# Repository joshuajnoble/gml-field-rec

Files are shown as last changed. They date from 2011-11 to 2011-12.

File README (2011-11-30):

WARNING: WORK IN PROGRESS...

configuring Eagle
-----------------

(B) setup environment in Eagle (library, schematic, layout)
  (1) in Eagle choose Options/Directories
  (2) add EAGLE diretory to Libraries (seperate paths with ':')
  (3) add EAGLE directory to Projects
  (4) in main Eagle window, under Projects, enable the fieldrec.lbr by clicking in the small grey circle (become green when enabled)

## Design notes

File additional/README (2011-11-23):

This library/code sample is to demonstrate writing GML to an SD card. I'd like to expand it to stream over RF as well. You do need to add one method to the WString class to get it work properly though:

char* c_str() { return _buffer; }

this mimics the c++ string method.

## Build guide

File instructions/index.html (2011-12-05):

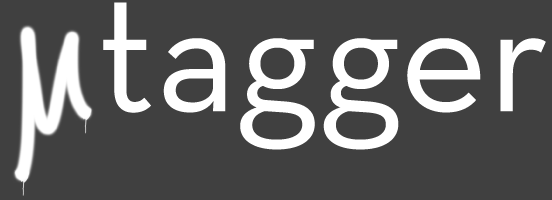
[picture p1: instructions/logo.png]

GML Field Recorder

# What Is This?

It's my entry for the GML Field Record Challenge which you can read more about here. What's GML you ask? Good question! Maybe this video will help:

So now you know a little about what GML is, you can understand why it would be cool to have something that could record GML out in the field, right? So what do we have? We got this:

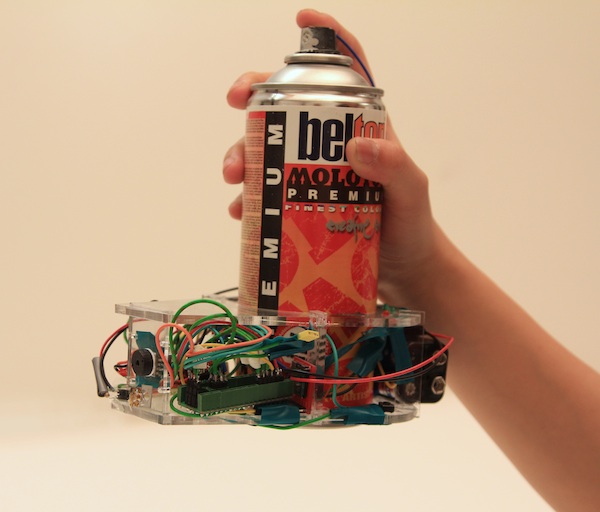
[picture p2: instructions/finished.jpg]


Looks crazy, right? I know. It kind of does. But it's also made to be built by anyone. Yes, anyone. Even you. So let's get down to it! First things first, you'll need to buy stuff.

# Buying Stuff

So you wanna make a μTagger GML Field Recorder? Great. First things first: you need to buy some electronics. The challenge says:

Material costs for the field device must not exceed 300 euros. Computers and equipment outside of the 300 euros can be used for non-field activities (such as downloading and manipulating data captured in-field), but at the time of capture a graffiti writer should have no more than 300 euros worth of equipment on him or herself.

Let's make a list in US Dollars, so I don't have to convert back everything I bought from US suppliers. We've got ~420.39$US to spend, so let's spend it.

- Teensy++2.0 $24
- ADNS5050 $1.47
- Ultrabright LED RED $4 example (http://www.sparkfun.com/products/9634)
- 2 100uF Ceramic Capacitors $1
- 2 1mF Capacitors $1
- Some Wires $3
- Sparkfun 9DOF $99 here (http://www.sparkfun.com/products/10724)
- 3 LEDs $2
- 2 220uF Capacitors $1
- 1 100uF Capacitor $0.50
- 1 1mO Resistor $0.50
- 1 Camera lens ~$10 (for the camera but you'll tear it apart)
- MicroSD card 2GB $4
- 1 3.3V Voltage Regulator $3
- MicroSD card holder $4 OR
- MicroSD card shield $10 here (http://www.sparkfun.com/products/544)
- Aluminum Foil $0.50
- Pushbutton $1

= $170.97 or 126.81 Euros
Not too shabby.
Where can I get this stuff?
Sparkfun (http://www.sparkfun.com/)
DigiKey (http://www.digikey.com/)
Mouser
RS

# How Does It Work?

Basic theory of operation goes like so: it's an optical mouse that knows how it's being tilted. We need to make sure that the mouse can read properly off the wall so we need to illuminate the wall properly, hence the ultra-bright Red LED. This one is 640nm, which is close enough to the 680nm that the ADNS5050 really wants. If you find a really bright 680nm LED that'll work even better. It needs to be big and bright though because we're working with a much larger area than the optical mouse is used to working with.

We point the mouse sensor and lens and LED at the wall and we get tracking. Easy right? Not really. There's a lot of fussing around to get the lens mounted correctly and aimed correctly at the optical mouse senors actual optical sensor. I got a lens that was f3.8, which is pretty perfect for what I want to do. You might get a different one, but if it's possible, stick with f3.8. Some of the keychain cameras come with f4.7 which isn't really going to work as well. We want something close up.

Making the lens mount is somewhat tricky and requires that you learn a little bit about the lens law depending on what the foal length of your lens is. As I mentioned, I'm using a f3.8 lens pulled out of a camera like the one shown below:

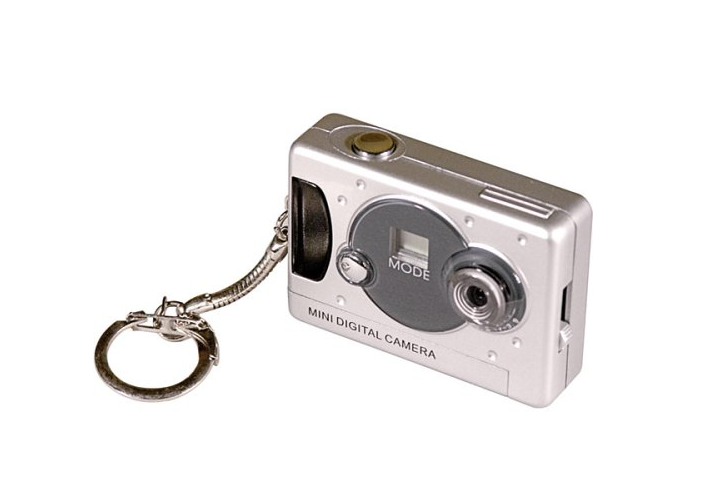
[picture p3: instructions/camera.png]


The lens law looks like this:



You can translate that as: 1/distance from lens to focal plane + 1/distance from lens to object = 1/focal length.

What that means is that whatever your lens is, f3.8, f4.9, whatever, you need to balance the equation with the reciprocal of the distance of the object to the lens plus the reciprocal of the distance of the lens to the focal plane. I've got mine set up a 5.25mm distance from between the lens and the ADNS5050 so that I can focus on things around 2.5cm away from the lens (do the math if you like). Whatever lens you decide to use, just make sure that the radius of the focal area is small. Those little keychain cameras are perfect, larger lenses, like the ones from the PS3 eye, aren't going to work. NOTE: the actual location of the optical sensor in the ADNS5050 is 2mm down from the top of the optical mouse sensor. See the picture here:

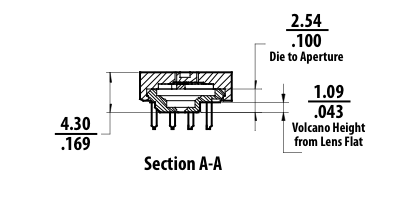
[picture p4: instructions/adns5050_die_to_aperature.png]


So your actual distance from the die to the aperature is 1mm from the start. You need to get 4.25 more mm for all to be happy.

# Cutting Stuff Up

I cut the lens mount and the ADNS5050 holder out of 2mm acrylic on a cheap shitty laser cutter. Works like a dream. The illustrator file is included. The difficulty is positioning the lens just right so that it's 5.25mm from the optical mouse sensor. I made a mount out of two pieces of two pieces of acrylic and put some little holes in them to ensure that everything lined up right.

Here's the cuts for the frame as they came out:

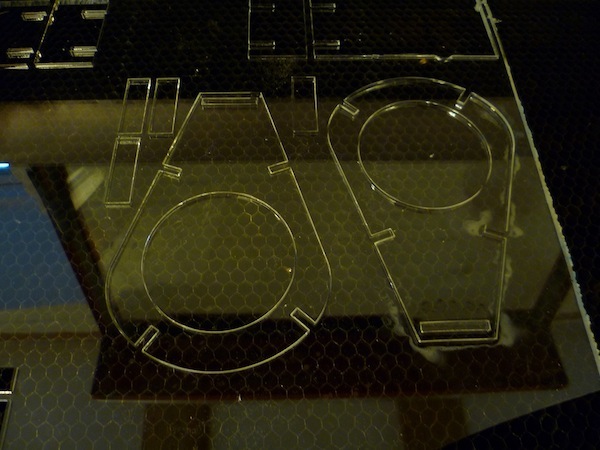
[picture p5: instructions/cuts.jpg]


Here's what the holders look like close up.

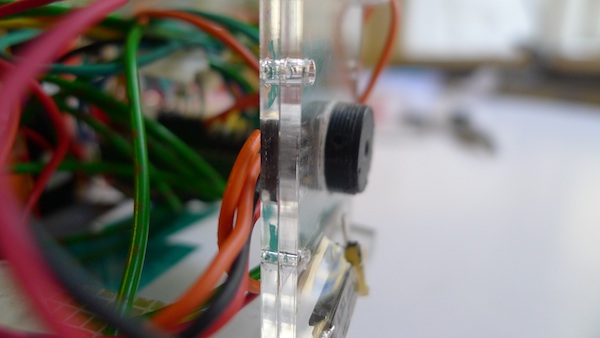
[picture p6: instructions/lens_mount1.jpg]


You can see how the ADNS5050 is behind the lens, with the wires soldered in place:

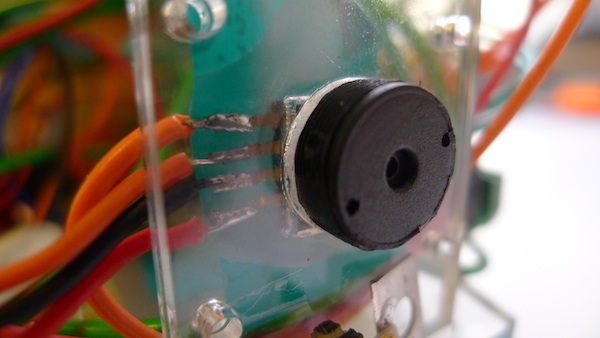
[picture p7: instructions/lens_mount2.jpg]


The lens mouse illustrator files are included as lens_mount.ai
The body of the field recorder is shown in shape_pattern.ai
It's fairly rough right now, v2 is going to have a better shaped body.

# Putting It Together

The Teensy sits on the body, with all the wiring and 4 AA batteries. The teensy can't handle a 9V battery, so don't plug one into it. The lens+ADNS assembly slots into the little cutout at the end. Right now I have it so it's fit tight with the 2 sheets of 2mm acrylic that make up my assembly, but whatever holds it perpendicular to the wall and doesn't allow it to move is just fine. The body is then slid over the bottom of the spray paint can and held into place with some pieces of tape. I also added some into place (tape not neccessary, but recommended).

The 9DOF is mounted along the side the can where there's room.

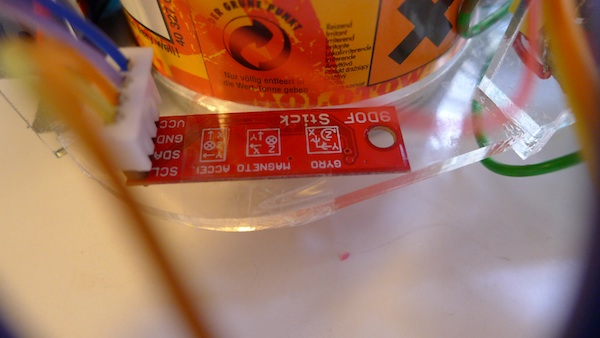
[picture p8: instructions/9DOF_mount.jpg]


It's pretty important how this thing is mounted because it affects the positioning data that you'll get back. In the code you might note this:

if(abs(p) > 0.1) /// some arbitrary-ish noise amount
{
xRot = sin(ypr[1] + (TWO_PI));
yRot = cos(ypr[1] + (TWO_PI));
position[0] += xRot;
position[1] -= yRot;

}

That's actually dependent on the positioning of the 9DOF so if you move it, those'll need to be different.

The capacitive sensor uses a piece of foil to read the touches when the user is actually making a line. You should put near the top of the can so that it's easy to spray and signal to the recorder that you're making a line at the same time. How about the actual tag trigger? Pretty straightforward:

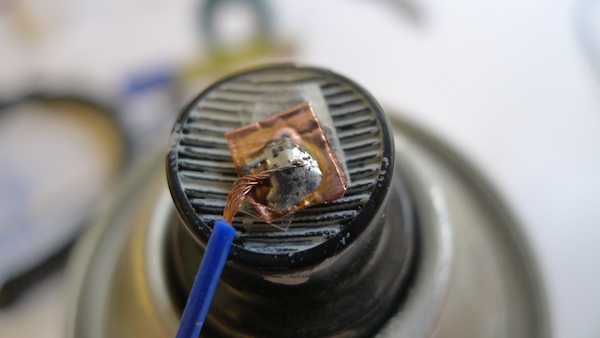
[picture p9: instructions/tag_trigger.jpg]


Yep, that's copper tape with a wire soldered to it and that's all you need.

# Using It

Here's the manual:

- Start up the field recorder by plugging in the battery.
- If the SD Card is full or there's another problem with it, the SD card LED is flashed 5 times to let you know. Otherwise, it illuminates for 1 second.
- When you press the toggle button, you start recording a tag. The recording light goes on to let you know that the tag is being recorded.
- When you press on the capacitive sensor the recording LED and the SD card LED will go on to let you know that the stroke is being recorded. When it's released the SD card LED goes out. This givs you an idea of what's going on in the recorder. You can use the surface quality LED to see how well your ADNS5050 is recognizing the surface. If the light is steadily illuminated, it's doing very well; the more slolwy the light blinks, the worse the signal quality and the worse the accuracy of your recorded tag will be.
- As you move the recorder around it's important to keep it oriented perpendicular to the wall. The beta version of the software will be much better about allowing you to move the recorder around a little more but for the moment the mouse sensor is the only thing really recording the position, so it's important that it works well. Right now the sensor is 0.5 centimeter precise when used correctly, but I'm working on it, and hopefully I'll get to mm precision soonish. Just a little bit more math and noise filtering to use the 9DOF better. If you've set the lens so that it should be focused at 2cm, then make sure you keep it at 2cm. Again, this is going to get better in the v2 or beta release, or whatever, but tat the moment it's a bit naive, so bear that in mind when making a tag.
- The surface quality light blinks slower and slower as the surface quality goes down. Your goal when operating the thing should be to keep the surface quality light as close to constantly illuminated as possible
- When you're done with your tag simply press the button again and you'll see the tag light either blink 3 times slowly for a happy write to file or 5 times quickly for a failed write to file.

# The Code

Most of the main application is contained in libraries. Everything in /libs goes in your Arduino/libraries
You need to add one method to the WString class to get it work properly though:

char* c_str() { return _buffer; }

this mimics the c++ string method. The WString.h lives where Arduino application lives, so Arduino/hardware/teensy/cores on Windows or Arduino.app/Resources/Java/hardware/teensy/cores on OSX. You can either add that manually or copy the files from /additional There are two extra config applications to help you position the lens correctly, an Arduino application and a Processing application (https://github.com/joshuajnoble/gml-field-rec/tree/master/configuration). The P5 app just reads the pixels from the ADNS5050 so you can focus the lens, check your positioning and the distance from the lens to the mouse sensor.

# The Future

- As mentioned, I need to make a better body for the thing.
- Make a video.
- Try out some different optical sensors like the ADNS9550 for higher resolution.
- I'm making an ipod/iPhone OF app that you can use with a simple chip plugged into the bottom of the iPhone to grab signals directly from the tagger and live log.
- We're building an eagle file to print an actual board instead of the DIY jiggedy-ness that we have at the moment.

# DOWNLOAD HERE (http://thefactoryfactory.com/GML_FR.zip)

# GITHUB HERE (https://github.com/joshuajnoble/gml-field-rec)

joshua noble 2011 no rights reserved, long live christiania

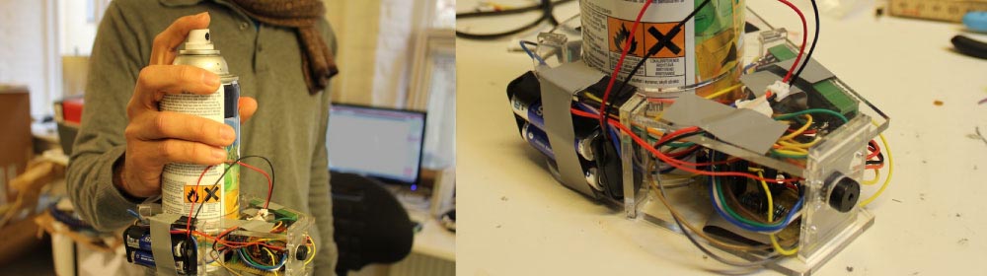
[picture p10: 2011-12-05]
instructions/headerbg.jpg

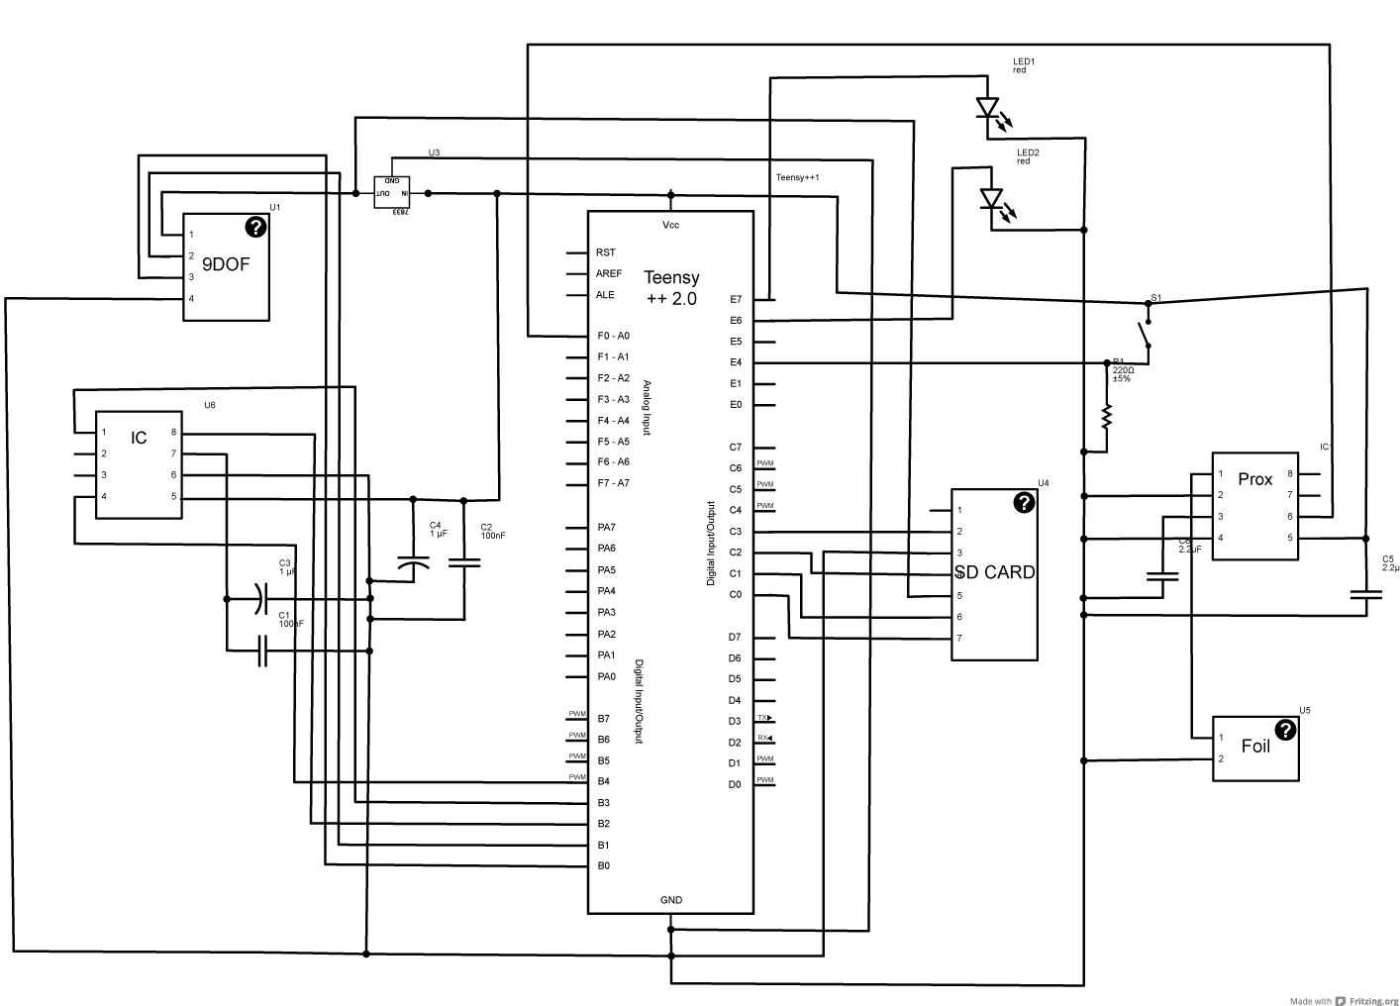
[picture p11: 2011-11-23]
wiring/gml_fieldrecorder_schem.png

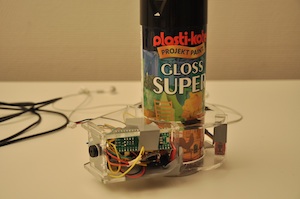
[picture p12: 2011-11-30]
instructions/header2.jpg

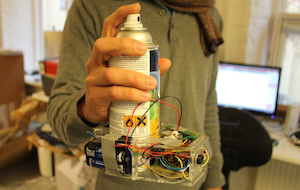
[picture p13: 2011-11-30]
instructions/header.png

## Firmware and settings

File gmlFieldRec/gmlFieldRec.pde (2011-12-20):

#include "ADNS5050.h"
#include "GMLWriter.h"
#include <Wire.h>
#include <ADXL345.h>
#include <HMC58X3.h>
#include <ITG3200.h>
#include <CapSense.h>

#include <SdFat.h>

// I'm using a Teensy 2.0, but you can use any 328 or higher board.
// You do need a bigger board to run this, anything with a 168 or Atmega8
// probably isn't going to cut it
#define __AVR_AT90USB1286__
// #define __AVR_ATmega328P__ // Arduino Uno

//#define DEBUG

//#ifdef DEBUG
//  const int CAP_LIM = 2000;
//#else ifndef DEBUG
  const int CAP_LIM = 500;
//#endif

#include "DebugUtils.h"
#include "FreeIMU.h"
#include "CommunicationUtils.h"

#define TAGGING_LED 33
#define SDCARD_LED 29
#define SQUAL_LED 28
#define TAG_PIN 32

#define SCLK                11
#define SDIO                10
#define RESET_PIN           12
#define NCS                 13

#define ILLUMINATION_LED 24
#define LASER_LED 19

// STATE
int state;

#define INIT 1
#define TAGGING 2
#define TAGGING_DOWN 3
#define FINISH_TAG 4

long debounce;

//#define CAN_HEIGHT_600ML 28.4 // height of a 600ML molotow can in CM
//#define CAN_HEIGHT_12OZ 26

//#define CAN_HEIGHT_600ML 14.2 // height of a 600ML molotow can in CM
#define CAN_HEIGHT_600ML 2

ADNS5050 omouse(SCLK, SDIO, NCS, RESET_PIN); // might want to shift this over to non-PWM pins?
GMLWriter gml;

// we'll just start at 2000 so we don't go negative
float position[2] = { 
  2000.0, 2000.0 };
int pposition[2];

float ypr[3] = { 0.0, 0.0, 0.0 };
float prevYpr[3];

// Set the FreeIMU object
FreeIMU imu = FreeIMU();

long tagStart;
int surfQuality;
long lastSurfBlink;
boolean squalPin;

CapSense listenCap = CapSense(34, 30);

void setup()
{

  //Serial.begin( 9600 );
  
  omouse.sync(); // this takes a second
  
  pinMode( LASER_LED, OUTPUT);
  pinMode( ILLUMINATION_LED, OUTPUT );
  pinMode(TAG_PIN, INPUT);

  pinMode(TAGGING_LED, OUTPUT);
  pinMode(SDCARD_LED, OUTPUT);
  pinMode(SQUAL_LED, OUTPUT);

  digitalWrite( SDCARD_LED, HIGH);
  delay(500);
  digitalWrite( SDCARD_LED, LOW);
  digitalWrite( TAGGING_LED, HIGH);
  delay(500);
  digitalWrite( TAGGING_LED, LOW);
  digitalWrite( SQUAL_LED, HIGH);
  delay(500);
  digitalWrite( SQUAL_LED, LOW);

  // SD CARD SET UP
  debounce = millis();

  int ret = gml.init();
  //Serial.print( ret );
  if(ret != 1) { // i.e. if it fails

    //Serial.println(" GML not intialized ");

    int i;
    for(i = 0; i<5; i++) { // 5 blinks = not ok
      digitalWrite( SDCARD_LED, HIGH);
      delay(250);
      digitalWrite( SDCARD_LED, LOW);
      delay(250);
    }
  } 
  else {
    digitalWrite( SDCARD_LED, HIGH);
    delay(2000);
    digitalWrite( SDCARD_LED, LOW);
  }

  state = INIT;
  
  // CAPSENSE setup
  listenCap.set_CS_Timeout_Millis(30);
  listenCap.set_CS_AutocaL_Millis(10);
  
  
  // FREEIMU set up
  Wire.begin();
  //Serial.println( " set pu  ");
  delay(5);
  imu.init(); // the parameter enable or disable fast mode
  delay(5);
}


void loop()
{

  if(state == INIT)
  {
    if(digitalRead(TAG_PIN) && millis() - debounce > 500) {

      debounce = millis();

      //Serial.println(" start tagging ");

      if( gml.beginDrawing() != 1 ) {
        
        //Serial.print(" can't begin drawing ");
        
        int i;
        for(i = 0; i<5; i++) { // 5 blinks = not ok
          digitalWrite( SDCARD_LED, HIGH);
          delay(500);
          digitalWrite( SDCARD_LED, LOW);
          delay(500);
        }
        return;
      }

      state = TAGGING;
      
      digitalWrite(TAGGING_LED, HIGH); // know you're tagging
      digitalWrite( ILLUMINATION_LED, HIGH );
      digitalWrite( LASER_LED, HIGH);

      return;
    }
  }
  else if (state == TAGGING)
  {
    //delay(10);
    ////Serial.println(" TAGGING ");
    tagStart = millis();

    if(digitalRead(TAG_PIN) && millis() - debounce > 500) {
      debounce = millis();
      //Serial.println(" tag pin ");
      state = FINISH_TAG;
    }
   
   byte sqty = omouse.surfaceQuality();
   if(sqty != -1) { // sometimes this just returns nothing
     surfQuality = 80 - (sqty * 4);
   }
   
    if(surfQuality < 2) {
      digitalWrite(SQUAL_LED, HIGH);
    } else if(millis() - lastSurfBlink > surfQuality) {
      lastSurfBlink = millis();
      digitalWrite(SQUAL_LED, squalPin);
      squalPin = !squalPin;
    }
    

    imu.getYawPitchRoll(ypr);
    determinePosition();
    
    int cap = listenCap.capSense(10);
    if(cap > CAP_LIM || cap < -1) // this is for my configuration, yrs may differ
    {
      digitalWrite(SDCARD_LED, HIGH);
      state = TAGGING_DOWN;
      gml.beginStroke();
    }
    
  }
  else if (state == TAGGING_DOWN)
  {
    determinePosition();

    ////Serial.println( omouse.surfaceQuality(), DEC );
    
   byte sqty = omouse.surfaceQuality();
   if(sqty > 0) { // sometimes this just returns nothing
     surfQuality = 80 - (sqty * 4);
   }
    
    if(surfQuality < 2) {
      digitalWrite(SQUAL_LED, HIGH);
    } else if(millis() - lastSurfBlink > surfQuality) {
      lastSurfBlink = millis();
      digitalWrite(SQUAL_LED, squalPin);
      squalPin = !squalPin;
    }
    
    int cap = listenCap.capSense(10);
    if(cap > CAP_LIM || cap < 0)
    {

      if( abs(pposition[0] - position[0]) > 1.0 ||  abs(pposition[1] - position[1]) > 1.0) {
        gml.addPoint(position[0], position[1], millis() - tagStart);
      }

      pposition[0] = position[0];
      pposition[1] = position[1];

    }
    else
    {
      digitalWrite(SDCARD_LED, LOW);
      debounce = millis();
      state = TAGGING;
      gml.endStroke();

    }
    
  }
  else if(state == FINISH_TAG)
  {
    //if(gml.endDrawing()) {

    digitalWrite( ILLUMINATION_LED, LOW );
    digitalWrite( LASER_LED, LOW);

    if(gml.endDrawing()) {

      //Serial.println(" FINISH_TAG OK ");

      digitalWrite(TAGGING_LED, LOW); // know you're tagging
      digitalWrite( SDCARD_LED, HIGH);
      delay(1000);
      digitalWrite( SDCARD_LED, LOW);
      delay(500);
      digitalWrite( SDCARD_LED, HIGH);
      delay(1000);
      digitalWrite( SDCARD_LED, LOW); // 2 blinks, it's ok


    } else {

      //Serial.println(" FINISH_TAG NOT OK ");

      digitalWrite(TAGGING_LED, LOW); // know you're tagging

      int i;
      for(i = 0; i<5; i++) { // 5 blinks = not ok
        digitalWrite( SDCARD_LED, HIGH);
        delay(500);
        digitalWrite( SDCARD_LED, LOW);
        delay(500);
      }
    }
    digitalWrite( SQUAL_LED, LOW);
    state = INIT;
  }
}

void determinePosition()
{

  position[0] -= omouse.dx() >> 1;
  position[1] -= omouse.dy() >> 1;

  float y, p, r;

  imu.getYawPitchRoll(&ypr[0]);

  y = prevYpr[0] - ypr[0];
  p = prevYpr[1] - ypr[1];
  r = prevYpr[2] - ypr[2];
  
  float xRot, yRot;

  if(abs(p) > 0.1) /// some arbitrary noise amount
  {
    //xRot = sin(ypr[1] * (PI/180.0) + (TWO_PI));
    //yRot = cos(ypr[1] * (PI/180.0) + (TWO_PI));

    xRot = sin(ypr[1] + (TWO_PI)) * CAN_HEIGHT_600ML;
    yRot = cos(ypr[1] + (TWO_PI)) * CAN_HEIGHT_600ML;
    
    position[0] -= xRot;
    position[1] -= yRot;
    
  }

  prevYpr[0] = ypr[0];
  prevYpr[1] = ypr[1];
  prevYpr[2] = ypr[2];

  /*Serial.print(ypr[1]);
  //Serial.print(" ");
  //Serial.print(position[0]);
  //Serial.print(" " );
  //Serial.println(position[1]);*/

}

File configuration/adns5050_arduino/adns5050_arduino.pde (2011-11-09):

#define SCLK                10
#define SDIO                11
#define RESET_PIN           12
#define NCS                 13
#define POWER               17

#define PRODUCTID          0x00 // should be 0x12
#define PRODUCTID2          0x3e //should be 0x26
#define REVISION_ID         0x01
#define DELTA_Y_REG         0x03
#define DELTA_X_REG         0x04
#define SQUAL_REG           0x05
#define MAXIMUM_PIXEL_REG   0x08
#define MINIMUM_PIXEL_REG   0x0a
#define PIXEL_SUM_REG       0x09
#define PIXEL_DATA_REG      0x0b
#define SHUTTER_UPPER_REG   0x06
#define SHUTTER_LOWER_REG   0x07
#define RESET		    0x3a
#define CPI500v		    0x00
#define CPI1000v	    0x01

#define NUM_PIXELS          360

#define MICROSEC_DELAY      10

byte pix[360];

const int LED_R = 26;
const int LED_L = 24;

void setup()
{
  Serial.begin(115200);

  pinMode(SDIO, OUTPUT);
  pinMode(SCLK, OUTPUT);
  pinMode(POWER, OUTPUT);
  
  pinMode(LED_R, OUTPUT);
  pinMode(LED_L, OUTPUT);
  
  digitalWrite(LED_R, HIGH);
  digitalWrite(LED_L, HIGH);

  digitalWrite(POWER, HIGH);

  pinMode(RESET_PIN, OUTPUT);
  digitalWrite(RESET_PIN, HIGH);

  sync();

  ADNS_write(RESET, 0x5a);
  delay(50); // From NRESET pull high to valid mo tion, assuming VDD and motion is present.

}

void loop()
{
  delay(100); 

  //Serial.println( ADNS_read(PRODUCTID2), HEX);

  pixelGrab();
}

void sync()
{
  pinMode(NCS, OUTPUT);
  digitalWrite(NCS, LOW);
  delayMicroseconds(2);
  digitalWrite(NCS, HIGH);
}

void ADNS_write(unsigned char addr, unsigned char data) 
{
  char temp;
  int n;

  digitalWrite(NCS, LOW);//nADNSCS = 0; // select the chip

  temp = addr | 0x80; // MOST RECENT

  digitalWrite(SCLK, LOW); //SCK = 0;					// start clock low
  pinMode(SDIO, OUTPUT); //DATA_OUT; // set data line for output
  for (n=0; n<8; n++) {
    digitalWrite(SCLK, LOW); //SCK = 0;
    pinMode(SDIO, OUTPUT);
    delayMicroseconds(MICROSEC_DELAY);
    if (temp & 0x80)
      digitalWrite(SDIO, HIGH); //SDOUT = 1;
    else
      digitalWrite(SDIO, LOW);//SDOUT = 0;
    temp = (temp << 1);
    digitalWrite(SCLK, HIGH);//SCK = 1;
    delayMicroseconds(MICROSEC_DELAY);//delayMicroseconds(1);			// short clock pulse
  }
  temp = data;
  for (n=0; n<8; n++) {
    delayMicroseconds(MICROSEC_DELAY);
    digitalWrite(SCLK, LOW);//SCK = 0;
    delayMicroseconds(MICROSEC_DELAY);
    if (temp & 0x80)
      digitalWrite(SDIO, HIGH);//SDOUT = 1;
    else
      digitalWrite(SDIO, LOW);//SDOUT = 0;
    temp = (temp << 1);
    digitalWrite(SCLK, HIGH);//SCK = 1;
    delayMicroseconds(1);			// short clock pulse
  }
  delayMicroseconds(20);
  digitalWrite(NCS, HIGH); //nADNSCS = 1; // de-select the chip
}

byte ADNS_read(unsigned char addr)
{
  byte temp;
  int n;

  digitalWrite(NCS, LOW); //nADNSCS = 0;				// select the chip
  temp = addr;
  digitalWrite(SCLK, OUTPUT); //SCK = 0  start clock low
  pinMode(SDIO, OUTPUT); //DATA_OUT set data line for output
  for (n=0; n<8; n++) {
    delayMicroseconds(MICROSEC_DELAY);
    digitalWrite(SCLK, LOW); //SCK = 0;
    delayMicroseconds(MICROSEC_DELAY);
    pinMode(SDIO, OUTPUT); //DATA_OUT;
    if (temp & 0x80) {
      digitalWrite(SDIO, HIGH); //SDOUT = 1;
    } 
    else {
      digitalWrite(SDIO, LOW); //SDOUT = 0;
    }
    delayMicroseconds(MICROSEC_DELAY);
    temp = (temp << 1);
    digitalWrite(SCLK, HIGH); //SCK = 1;
  }

  temp = 0; // This is a read, switch to input
  pinMode(SDIO, INPUT); //DATA_IN;
  for (n=0; n<8; n++) { // read back the data
    delayMicroseconds(MICROSEC_DELAY);
    digitalWrite(SCLK, LOW);
    delayMicroseconds(MICROSEC_DELAY);
    if(digitalRead(SDIO)) { // got a '1'
      temp |= 0x1;
    }
    if( n != 7) temp = (temp << 1); // shift left
    delayMicroseconds(MICROSEC_DELAY);
    digitalWrite(SCLK, HIGH);
  }
  delayMicroseconds(20);
  digitalWrite(NCS, HIGH);// de-select the chip
  return temp;
}

byte ADNS_readPix(unsigned char addr)
{
  byte temp;
  int n;

  digitalWrite(NCS, LOW); //nADNSCS = 0 select the chip
  temp = addr;
  digitalWrite(SCLK, HIGH); //SCK = 0 start clock low
  pinMode(SDIO, OUTPUT); //DATA_OUT set data line for output

  for (n=0; n<8; n++) {
    digitalWrite(SCLK, LOW); //SCK = 0;
    delayMicroseconds(MICROSEC_DELAY);
    if (temp & 0x80) {
      digitalWrite(SDIO, HIGH); //SDOUT = 1;
    } 
    else {
      digitalWrite(SDIO, LOW); //SDOUT = 0;
    }
    temp = (temp << 1);
    //delayMicroseconds(1);
    digitalWrite(SCLK, HIGH); //SCK = 1;
    delayMicroseconds(MICROSEC_DELAY); // short clock pulse
  }

  temp = 0; // This is a read, switch to input

  pinMode(SDIO, INPUT); //DATA_IN;
  for (n=0; n < 7; n++) { // read back the data
    digitalWrite(SCLK, LOW);
    delayMicroseconds(MICROSEC_DELAY);
    if(digitalRead(SDIO)) { // got a '1'
      temp |= 0x1;
    }
    digitalWrite(SCLK, HIGH);
    delayMicroseconds(MICROSEC_DELAY);
    if( n != 6 ) temp = (temp << 1); // shift left
  }

  digitalWrite(NCS, HIGH);// de-select the chip
  return temp;
}

void pixelGrab()
{
  ADNS_write(PIXEL_DATA_REG, 1);
  int grabCount = 0; 
  while( grabCount < NUM_PIXELS )
  {
    Serial.print(ADNS_readPix(PIXEL_DATA_REG), BYTE);
    delay(1);
    grabCount++;
  }
  Serial.write('0');
}

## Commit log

2011-11-14 adding a fix for GML4U parsing since arduino can't do all the FP math to normalize coords on it's own
    [gmlFieldRec.pde]
2011-11-14 fixing absolutely awful bug. sclk was not being set to output. going to bed ashamed.
    [ADNS5050.cpp, gmlFieldRec.pde]
2011-11-16 some fixes to the coordinates, will be adding squal LED tomorrow
    [ADNS5050.cpp, gmlFieldRec.pde]
2011-11-23 adding eagle and build/wiring info
    [field_recorder.brd, field_recorder.sch, gml_fieldrecorder.fz]
2011-11-23 haha! commit
    + .gitignore
    + README
    [field_recorder.brd, field_recorder.sch]
2011-11-23 updated refs to new fieldrec.lbr in schematic + layout
    [field_recorder.brd, field_recorder.sch]
2011-11-23 adns-5050
    ~ fieldrec.lbr
    [field_recorder.brd, field_recorder.sch]
2011-11-24 power components added to lbr
    ~ fieldrec.lbr (MCP1252/3, MCP7383/4)
    [field_recorder.brd, field_recorder.sch]
2011-12-04 some IMU cleanup
2011-12-20 adding reference schematic for adns9500
    [adns9500-teardrops.brd, adns9500.brd, adns9500.sch]
2012-02-20 added AT90USB1286
    and deleted the old atmega329 and ft232
    [field_recorder.sch]
2012-02-20 commit to pull new version
    [field_recorder.brd]
